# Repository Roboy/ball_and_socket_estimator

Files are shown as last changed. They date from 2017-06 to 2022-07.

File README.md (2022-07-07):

# Neural network ball socket estimator

## Install

* Pytorch `conda install pytorch torchvision torchaudio cudatoolkit=10.2 -c pytorch`

* `pip install -r requirements.txt`

## Data collection

Switch to `python` folder as your working directory `cd python`

* Generate data using `python particle_swarm.py --body_part BODY_PART`
  
 with `BODY_PART = {head, shoulder_left, shoulder_right, hand_left, hand_right}`

* Topics to record:

    - `/roboy/pinky/sensing/external_joint_states`
    - `/roboy/pinky/middleware/MagneticSensor`
    - `/tracking_loss`
    - `/roboy/pinky/control/cardsflow_joint_states`
    - `/roboy/pinky/simulation/joint_targets`

## Training

* Convert `bags` to `csv` using `write_dataset_from_bag.ipynb`

* Run `data_analysis.ipynb` to make sure all the inputs and outputs are correct

* Train an LSTM network using `training.ipynb`

## Prediction
`cd python`
* Run the trained network `python predict_lstm.py`

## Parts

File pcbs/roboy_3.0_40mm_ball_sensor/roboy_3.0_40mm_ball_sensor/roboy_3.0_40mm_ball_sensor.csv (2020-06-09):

Id | Designator | Package | Quantity | Designation | Supplier and ref
1 | U1,U2,U3,U4 | TLE493d | 4 | TLE493d | https://www.mouser.de/ProductDetail/Infineon-Technologies/TLE493DW2B6A0HTSA1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
2 | C1,C2,C3,C4 | C_0402_1005Metric | 4 | C | Any – 5V compliant
3 | J1 | TE-Connectivity_Micro-Match_connector_02x05_Pitch_1.27mm | 1 | Conn_01x10_Female | https://www.mouser.de/ProductDetail/TE-Connectivity/1-2178710-0
8 | FID1 | Fiducial_0.5mm_Mask1mm | 1 | FID1
9 | FID2 | Fiducial_0.5mm_Mask1mm | 1 | FID2
10 | FID3 | Fiducial_0.5mm_Mask1mm | 1 | FID3

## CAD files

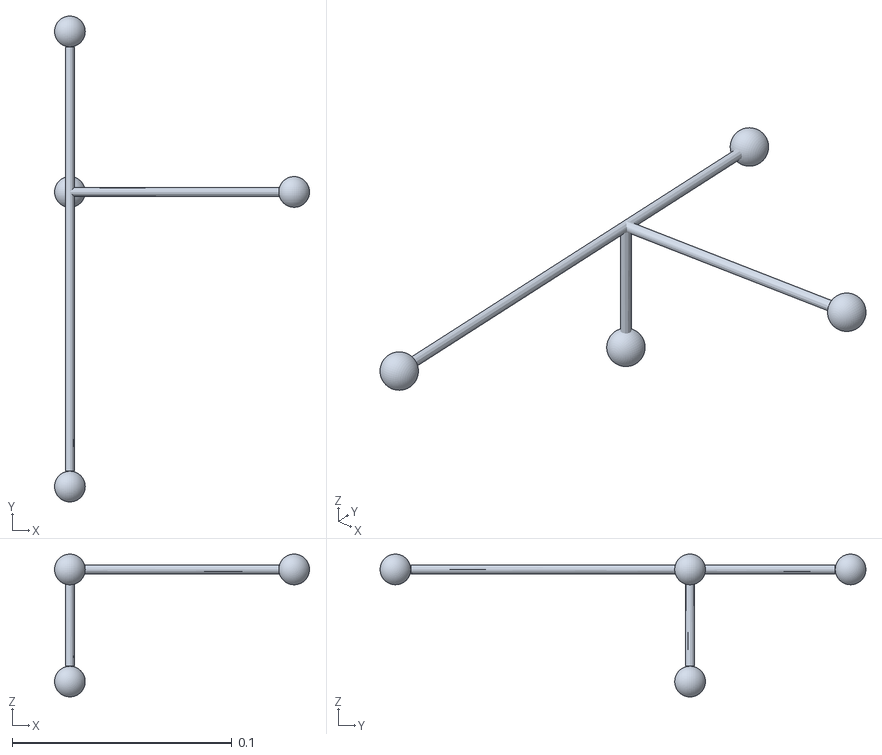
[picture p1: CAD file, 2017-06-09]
models/markermodel.STL
0.116 x 0.221 x 0.065

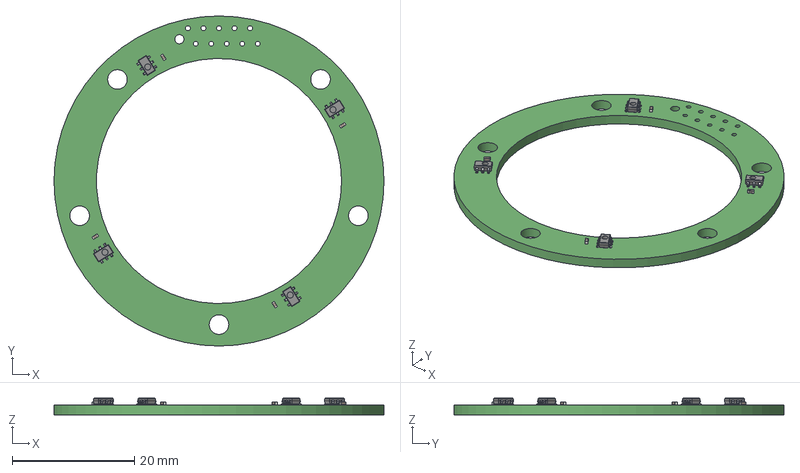
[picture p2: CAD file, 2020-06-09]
pcbs/roboy_3.0_40mm_ball_sensor/roboy_3.0_40mm_ball_sensor.step
54.0 x 54.0 x 2.75 mm

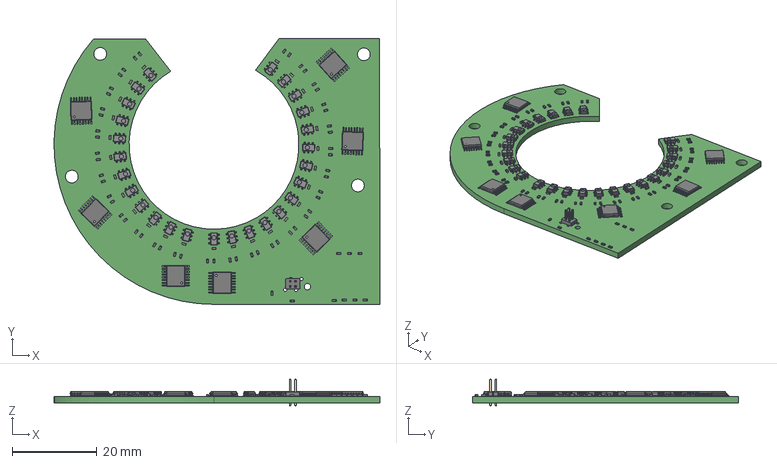
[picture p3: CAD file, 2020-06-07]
pcbs/roboy_3.0_40mm_magnetic_field_calibration/roboy_3.0_40mm_magnetic_field_calibration.step
76.8 x 62.6 x 6.30 mm

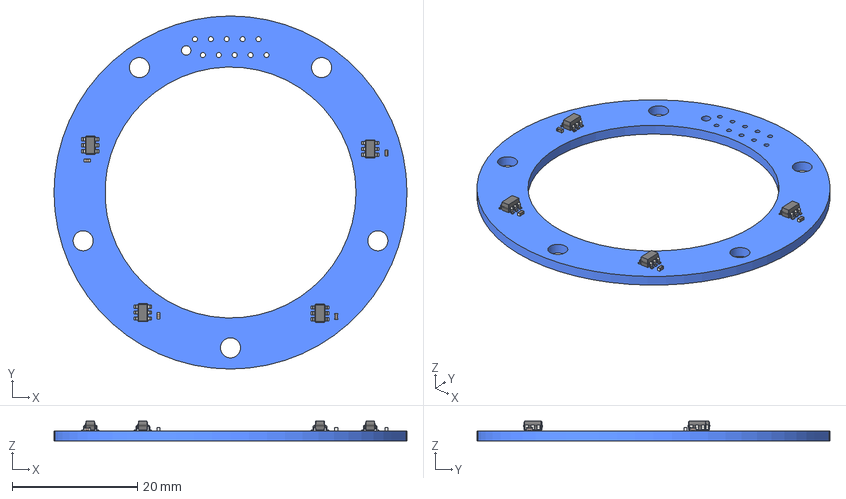
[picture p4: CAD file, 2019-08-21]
pcbs/roboy_3.0_40mm_ball_sensor/roboy_3.0_40mm_ball_sensor1.step
56.4 x 56.4 x 3.15 mm
Pcb
SOT_23_6_
SOT_23_6_001
SOT_23_6_002
C_0402_1005Metric_
C_0402_1005Metric_001
C_0402_1005Metric_002
C_0402_1005Metric_003
SOT_23_6_003

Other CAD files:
models/markermodel.obj

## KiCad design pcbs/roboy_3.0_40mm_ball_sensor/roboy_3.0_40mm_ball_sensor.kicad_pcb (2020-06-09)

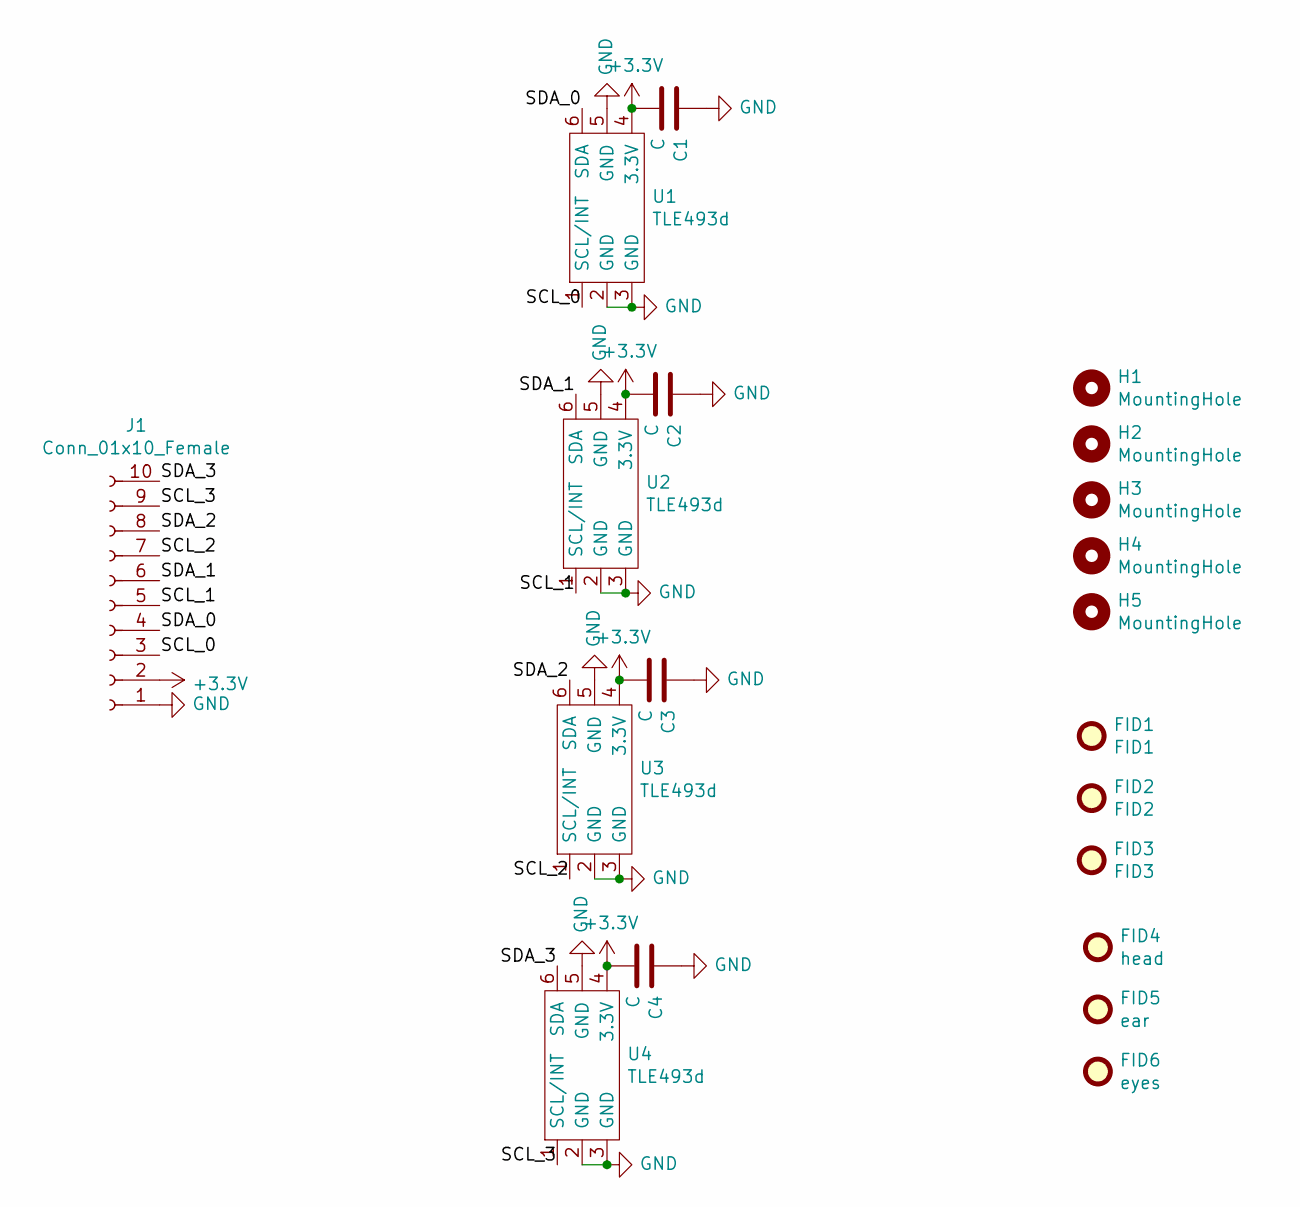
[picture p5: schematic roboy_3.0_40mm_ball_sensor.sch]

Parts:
C1, C2, C3, C4: C; C_0402_1005Metric
FID1: FID1; Fiducial_0.5mm_Mask1mm
FID2: FID2; Fiducial_0.5mm_Mask1mm
FID3: FID3; Fiducial_0.5mm_Mask1mm
FID4: head; R1_face_mask_5.5mm
FID5: ear; R1_ear_silk_5.5mm
FID6: eyes; R1_eyes_mask_5.5mm
H1, H2, H3, H4, H5: MountingHole; MountingHole_3.2mm_M3
J1: Conn_01x10_Female; TE-Connectivity_Micro-Match_connector_02x05_Pitch_1.27mm
U1, U2, U3, U4: TLE493d

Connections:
+3V3: C1.2, C2.2, C3.2, C4.2, J1.2, U1.4 (3.3V), U2.4 (3.3V), U3.4 (3.3V), U4.4 (3.3V)
/SCL_0: J1.3, U1.1 (SCL/INT)
/SCL_1: J1.5, U2.1 (SCL/INT)
/SCL_2: J1.7, U3.1 (SCL/INT)
/SCL_3: J1.9, U4.1 (SCL/INT)
/SDA_0: J1.4, U1.6 (SDA)
/SDA_1: J1.6, U2.6 (SDA)
/SDA_2: J1.8, U3.6 (SDA)
/SDA_3: J1.10, U4.6 (SDA)
GND: C1.1, C2.1, C3.1, C4.1, J1.1, U1.2 (GND), U1.3 (GND), U1.5 (GND), U2.2 (GND), U2.3 (GND), U2.5 (GND), U3.2 (GND), U3.3 (GND), U3.5 (GND), U4.2 (GND), U4.3 (GND), U4.5 (GND)

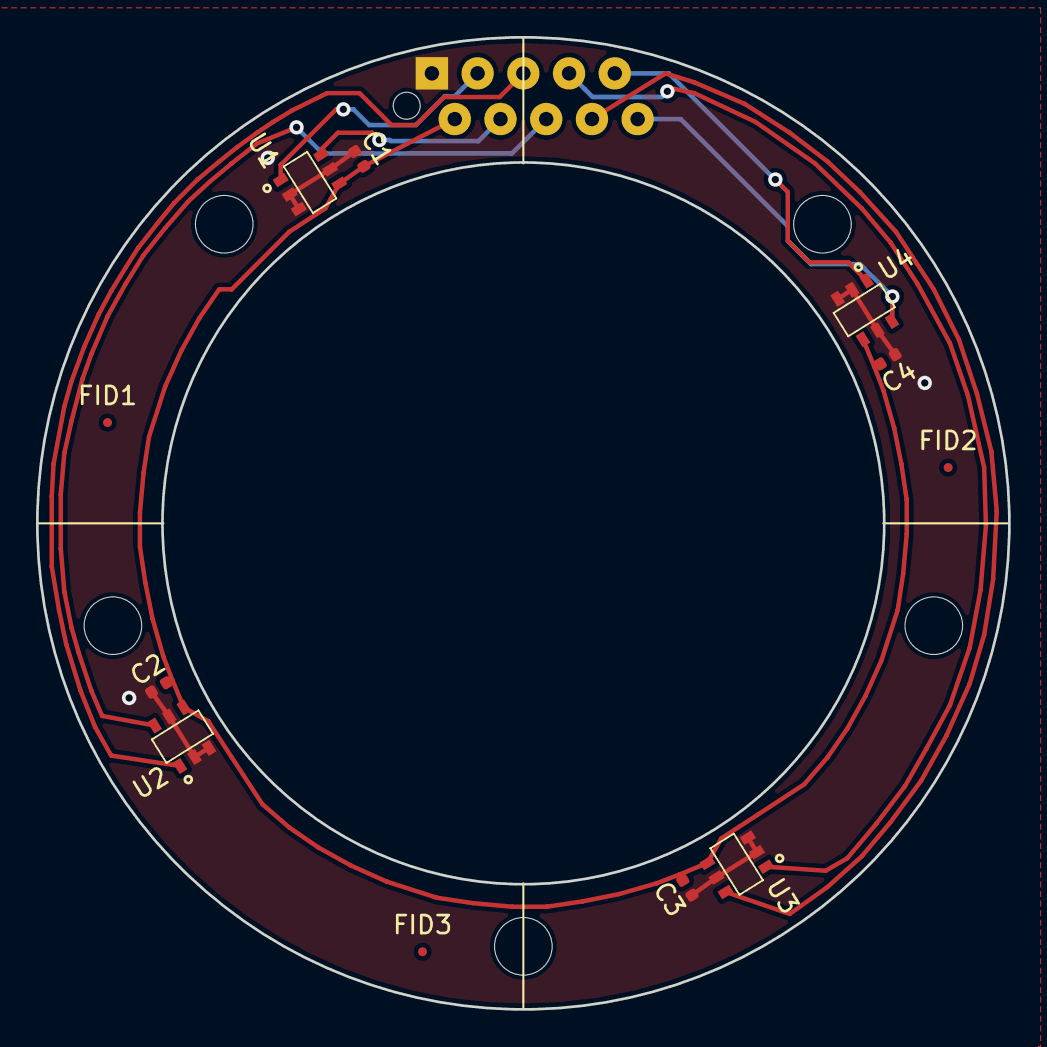
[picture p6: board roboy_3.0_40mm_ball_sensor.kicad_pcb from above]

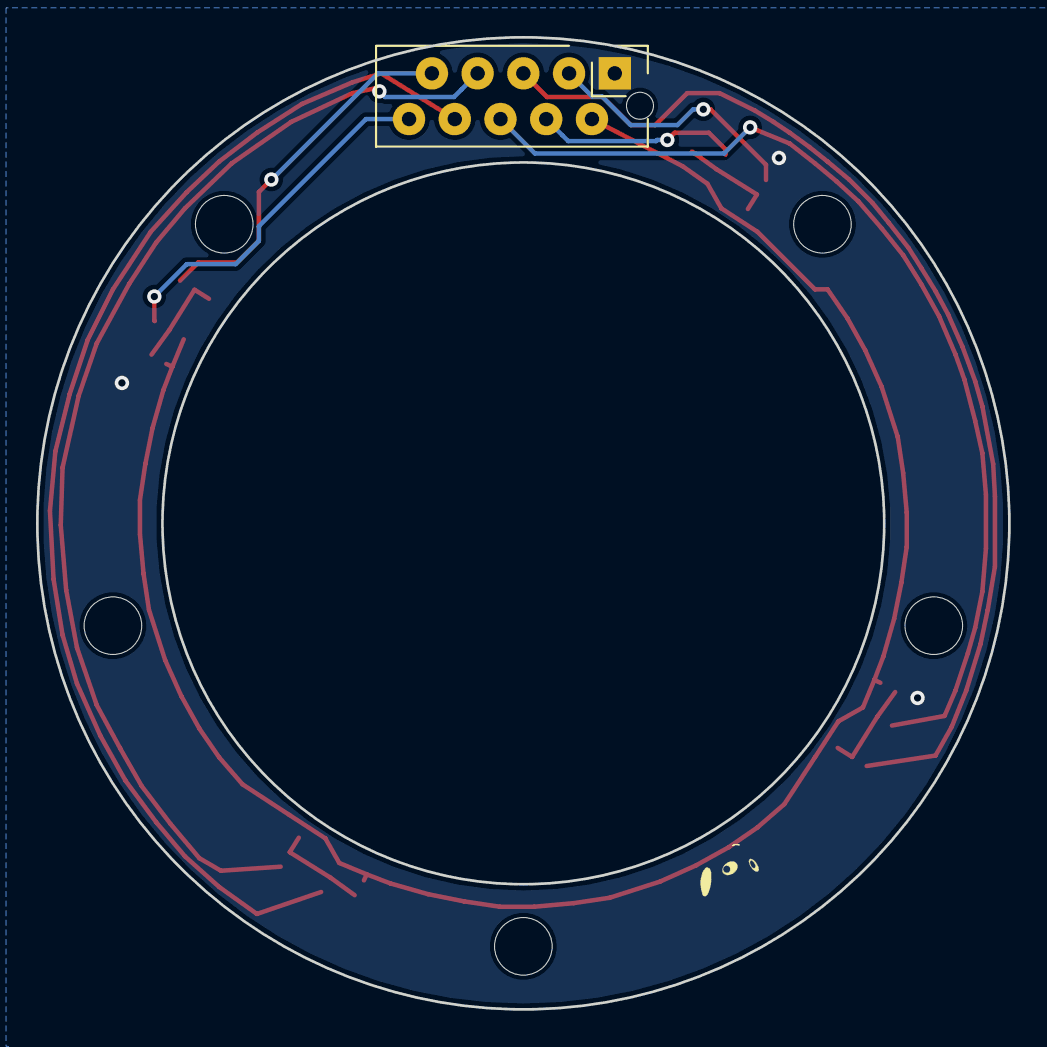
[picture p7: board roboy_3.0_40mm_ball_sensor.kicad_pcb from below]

Board: 2 copper layers, 54.0 x 54.0 mm, 20 parts (4 on the bottom side), 10 nets.

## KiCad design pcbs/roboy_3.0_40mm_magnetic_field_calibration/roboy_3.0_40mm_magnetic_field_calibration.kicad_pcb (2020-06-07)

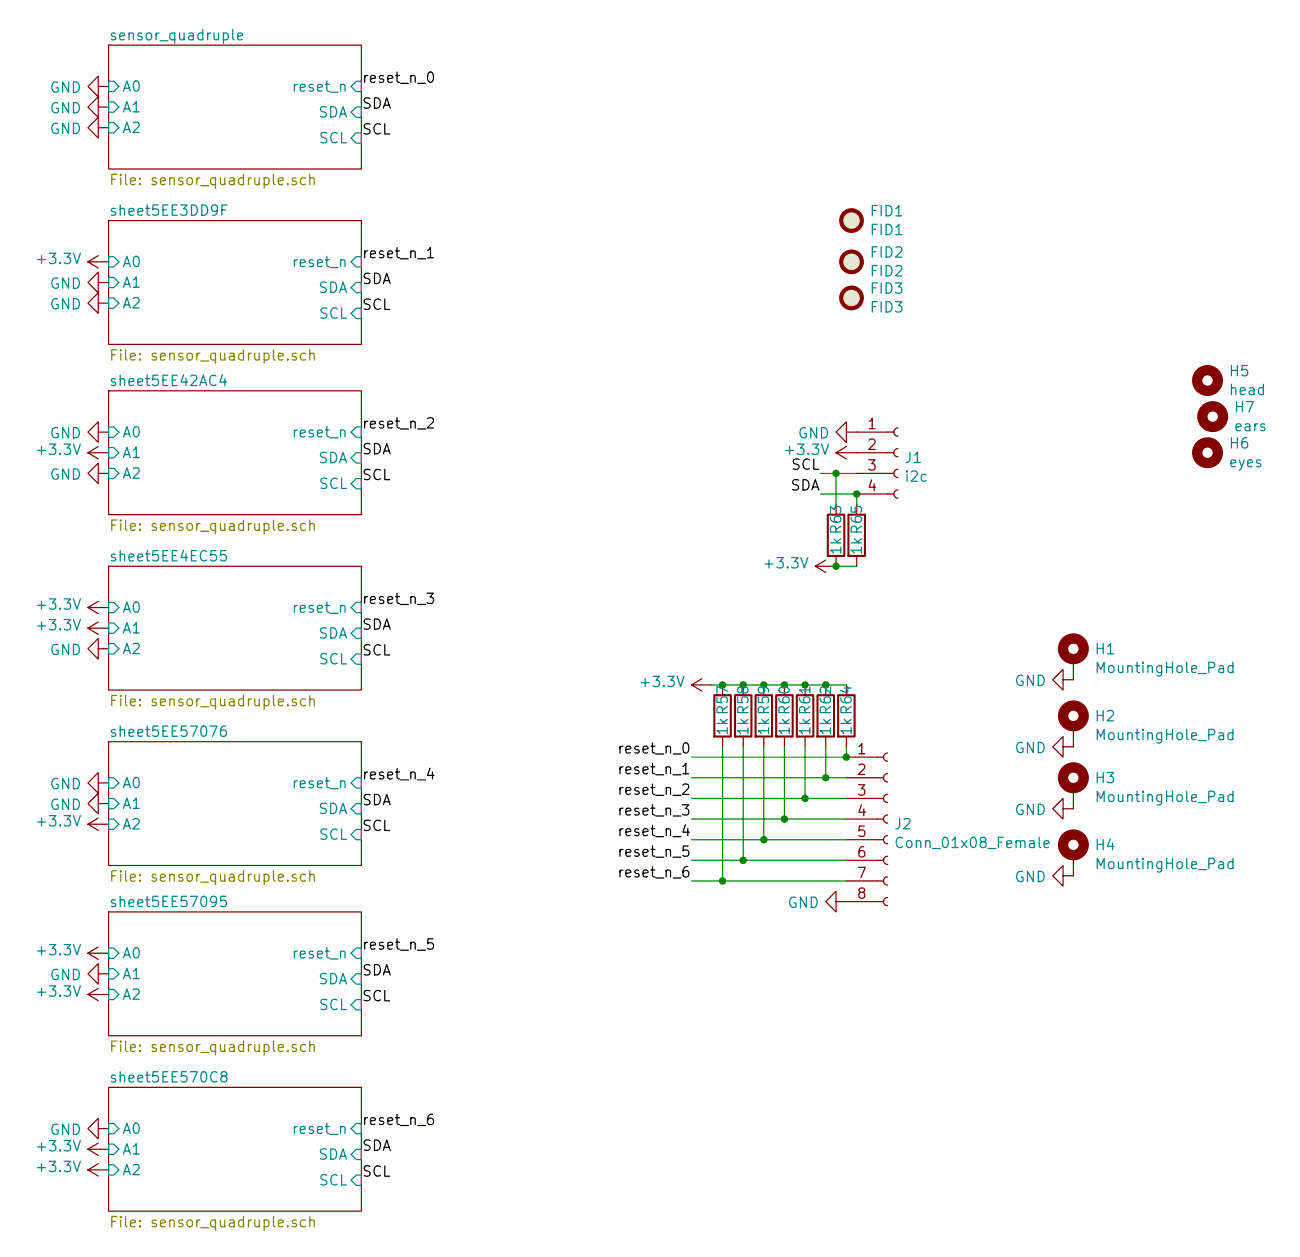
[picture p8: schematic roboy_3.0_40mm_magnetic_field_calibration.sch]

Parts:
FID1: FID1; Fiducial_0.75mm_Mask1.5mm
FID2: FID2; Fiducial_0.75mm_Mask1.5mm
FID3: FID3; Fiducial_0.75mm_Mask1.5mm
H1, H2, H3, H4: MountingHole_Pad; MountingHole_3mm_Pad
H5: head; R1_face_mask_5.5mm
H6: eyes; R1_eyes_mask_5.5mm
H7: ears; R1_ear_silk_5.5mm
J1: i2c; TE-Connectivity_Micro-Match_connector_02x02_Pitch_1.27mm
J2: Conn_01x08_Female; micro_match_female_8pos_SMT
R57, R58, R59, R60, R61, R62, R63, R64, R65: 1k; R_0402_1005Metric

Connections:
+3V3: J1.2, R57.1, R58.1, R59.1, R60.1, R61.1, R62.1, R63.2, R64.1, R65.2; also elsewhere on the board
/SCL: J1.3, R63.1; also elsewhere on the board
/SDA: J1.4, R65.1; also elsewhere on the board
/reset_n_0: J2.1, R64.2; also elsewhere on the board
/reset_n_1: J2.2, R62.2; also elsewhere on the board
/reset_n_2: J2.3, R61.2; also elsewhere on the board
/reset_n_3: J2.4, R60.2; also elsewhere on the board
/reset_n_4: J2.5, R59.2; also elsewhere on the board
/reset_n_5: J2.6, R58.2; also elsewhere on the board
/reset_n_6: J2.7, R57.2; also elsewhere on the board
GND: H1.1, H2.1, H3.1, H4.1, J1.1, J2.8; also elsewhere on the board

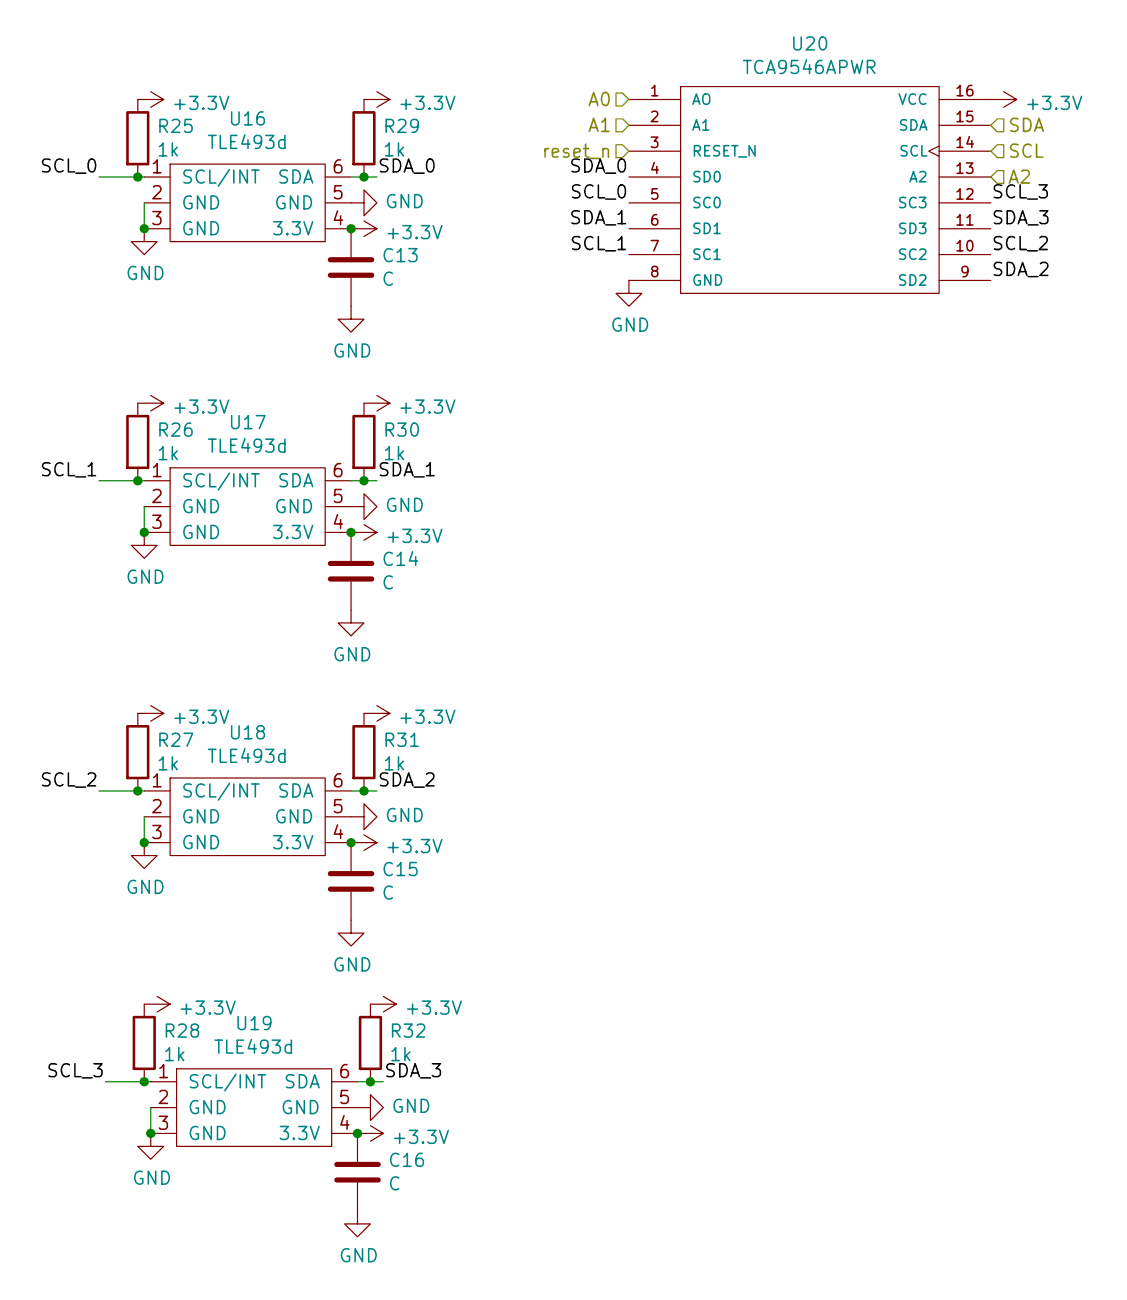
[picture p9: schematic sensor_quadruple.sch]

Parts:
C1, C2, C3, C4: C; C_0402_1005Metric
R1, R2, R3, R4, R5, R6, R7, R8: 1k; R_0402_1005Metric
U1, U2, U3, U4: TLE493d
U5: TCA9546APWR; SOP65P640X120-16N

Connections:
+3V3: C1.1, C2.1, C3.1, C4.1, R1.1, R2.1, R3.1, R4.1, R5.1, R6.1, R7.1, R8.1, U1.4 (3.3V), U2.4 (3.3V), U3.4 (3.3V), U4.4 (3.3V), U5.16 (VCC); also elsewhere on the board
/SCL: U5.14 (SCL); also elsewhere on the board
/SDA: U5.15 (SDA); also elsewhere on the board
/reset_n_0: U5.3 (RESET_N); also elsewhere on the board
/sensor_quadruple/SCL_0: R1.2, U1.1 (SCL/INT), U5.5 (SC0)
/sensor_quadruple/SCL_1: R2.2, U2.1 (SCL/INT), U5.7 (SC1)
/sensor_quadruple/SCL_2: R3.2, U3.1 (SCL/INT), U5.10 (SC2)
/sensor_quadruple/SCL_3: R4.2, U4.1 (SCL/INT), U5.12 (SC3)
/sensor_quadruple/SDA_0: R5.2, U1.6 (SDA), U5.4 (SD0)
/sensor_quadruple/SDA_1: R6.2, U2.6 (SDA), U5.6 (SD1)
/sensor_quadruple/SDA_2: R7.2, U3.6 (SDA), U5.9 (SD2)
/sensor_quadruple/SDA_3: R8.2, U4.6 (SDA), U5.11 (SD3)
GND: C1.2, C2.2, C3.2, C4.2, U1.2 (GND), U1.3 (GND), U1.5 (GND), U2.2 (GND), U2.3 (GND), U2.5 (GND), U3.2 (GND), U3.3 (GND), U3.5 (GND), U4.2 (GND), U4.3 (GND), U4.5 (GND), U5.1 (AO), U5.2 (A1), U5.8 (GND), U5.13 (A2); also elsewhere on the board

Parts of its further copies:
C5, C6, C7, C8, C9, C10, C11, C12, C13, C14, C15, C16, C17, C18, C19, C20, C21, C22, C23, C24, C25, C26, C27, C28: C; C_0402_1005Metric
R9, R10, R11, R12, R13, R14, R15, R16, R17, R18, R19, R20, R21, R22, R23, R24, R25, R26, R27, R28, R29, R30, R31, R32, R33, R34, R35, R36, R37, R38, R39, R40, R41, R42, R43, R44, R45, R46, R47, R48, R49, R50, R51, R52, R53, R54, R55, R56: 1k; R_0402_1005Metric
U6, U7, U8, U9, U11, U12, U13, U14, U16, U17, U18, U19, U21, U22, U23, U24, U26, U27, U28, U29, U31, U32, U33, U34: TLE493d
U10, U15, U20, U25, U30, U35: TCA9546APWR; SOP65P640X120-16N

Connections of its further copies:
+3V3: C5.1, C6.1, C7.1, C8.1, C9.1, C10.1, C11.1, C12.1, C13.1, C14.1, C17.1, C18.1, C19.1, C20.1, C21.1, C22.1, C23.1, C24.1, C25.1, C26.1, C27.1, C28.1, R9.1, R10.1, R11.1, R12.1, R13.1, R14.1, R15.1, R16.1, R17.1, R18.1, R19.1, R20.1, R21.1, R22.1, R23.1, R24.1, R25.1, R26.1, R29.1, R30.1, R33.1, R34.1, R35.1, R36.1, R37.1, R38.1, R39.1, R40.1, R41.1, R42.1, R43.1, R44.1, R45.1, R46.1, R47.1, R48.1, R49.1, R50.1, R51.1, R52.1, R53.1, R54.1, R55.1, R56.1, U6.4 (3.3V), U7.4 (3.3V), U8.4 (3.3V), U9.4 (3.3V), U10.1 (AO), U10.16 (VCC), U11.4 (3.3V), U12.4 (3.3V), U13.4 (3.3V), U14.4 (3.3V), U15.2 (A1), U15.16 (VCC), U16.4 (3.3V), U17.4 (3.3V), U20.1 (AO), U20.2 (A1), U20.16 (VCC), U21.4 (3.3V), U22.4 (3.3V), U23.4 (3.3V), U24.4 (3.3V), U25.13 (A2), U25.16 (VCC), U26.4 (3.3V), U27.4 (3.3V), U28.4 (3.3V), U29.4 (3.3V), U30.1 (AO), U30.13 (A2), U30.16 (VCC), U31.4 (3.3V), U32.4 (3.3V), U33.4 (3.3V), U34.4 (3.3V), U35.2 (A1), U35.13 (A2), U35.16 (VCC); also elsewhere on the board
/SCL: U10.14 (SCL), U15.14 (SCL), U20.14 (SCL), U25.14 (SCL), U30.14 (SCL), U35.14 (SCL); also elsewhere on the board
/SDA: U10.15 (SDA), U15.15 (SDA), U20.15 (SDA), U25.15 (SDA), U30.15 (SDA), U35.15 (SDA); also elsewhere on the board
/reset_n_1: U10.3 (RESET_N); also elsewhere on the board
/reset_n_2: U15.3 (RESET_N); also elsewhere on the board
/reset_n_3: U20.3 (RESET_N); also elsewhere on the board
/reset_n_4: U25.3 (RESET_N); also elsewhere on the board
/reset_n_5: U30.3 (RESET_N); also elsewhere on the board
/reset_n_6: U35.3 (RESET_N); also elsewhere on the board
/sheet5EE3DD9F/SCL_0: R9.2, U6.1 (SCL/INT), U10.5 (SC0)
/sheet5EE3DD9F/SCL_1: R10.2, U7.1 (SCL/INT), U10.7 (SC1)
/sheet5EE3DD9F/SCL_2: R11.2, U8.1 (SCL/INT), U10.10 (SC2)
/sheet5EE3DD9F/SCL_3: R12.2, U9.1 (SCL/INT), U10.12 (SC3)
/sheet5EE3DD9F/SDA_0: R13.2, U6.6 (SDA), U10.4 (SD0)
/sheet5EE3DD9F/SDA_1: R14.2, U7.6 (SDA), U10.6 (SD1)
/sheet5EE3DD9F/SDA_2: R15.2, U8.6 (SDA), U10.9 (SD2)
/sheet5EE3DD9F/SDA_3: R16.2, U9.6 (SDA), U10.11 (SD3)
/sheet5EE4EC55/SCL_0: R25.2, U16.1 (SCL/INT), U20.5 (SC0)
/sheet5EE4EC55/SCL_1: R26.2, U17.1 (SCL/INT), U20.7 (SC1)
/sheet5EE4EC55/SCL_2: U20.10 (SC2)
/sheet5EE4EC55/SCL_3: U20.12 (SC3)
/sheet5EE4EC55/SDA_0: R29.2, U16.6 (SDA), U20.4 (SD0)
/sheet5EE4EC55/SDA_1: R30.2, U17.6 (SDA), U20.6 (SD1)
/sheet5EE4EC55/SDA_2: U20.9 (SD2)
/sheet5EE4EC55/SDA_3: U20.11 (SD3)
/sheet5EE42AC4/SCL_0: R17.2, U11.1 (SCL/INT), U15.5 (SC0)
/sheet5EE42AC4/SCL_1: R18.2, U12.1 (SCL/INT), U15.7 (SC1)
/sheet5EE42AC4/SCL_2: R19.2, U13.1 (SCL/INT), U15.10 (SC2)
/sheet5EE42AC4/SCL_3: R20.2, U14.1 (SCL/INT), U15.12 (SC3)
/sheet5EE42AC4/SDA_0: R21.2, U11.6 (SDA), U15.4 (SD0)
/sheet5EE42AC4/SDA_1: R22.2, U12.6 (SDA), U15.6 (SD1)
/sheet5EE42AC4/SDA_2: R23.2, U13.6 (SDA), U15.9 (SD2)
/sheet5EE42AC4/SDA_3: R24.2, U14.6 (SDA), U15.11 (SD3)
/sheet5EE570C8/SCL_0: R49.2, U31.1 (SCL/INT), U35.5 (SC0)
/sheet5EE570C8/SCL_1: R50.2, U32.1 (SCL/INT), U35.7 (SC1)
/sheet5EE570C8/SCL_2: R51.2, U33.1 (SCL/INT), U35.10 (SC2)
/sheet5EE570C8/SCL_3: R52.2, U34.1 (SCL/INT), U35.12 (SC3)
/sheet5EE570C8/SDA_0: R53.2, U31.6 (SDA), U35.4 (SD0)
/sheet5EE570C8/SDA_1: R54.2, U32.6 (SDA), U35.6 (SD1)
/sheet5EE570C8/SDA_2: R55.2, U33.6 (SDA), U35.9 (SD2)
/sheet5EE570C8/SDA_3: R56.2, U34.6 (SDA), U35.11 (SD3)
/sheet5EE57076/SCL_0: R33.2, U21.1 (SCL/INT), U25.5 (SC0)
/sheet5EE57076/SCL_1: R34.2, U22.1 (SCL/INT), U25.7 (SC1)
/sheet5EE57076/SCL_2: R35.2, U23.1 (SCL/INT), U25.10 (SC2)
/sheet5EE57076/SCL_3: R36.2, U24.1 (SCL/INT), U25.12 (SC3)
/sheet5EE57076/SDA_0: R37.2, U21.6 (SDA), U25.4 (SD0)
/sheet5EE57076/SDA_1: R38.2, U22.6 (SDA), U25.6 (SD1)
/sheet5EE57076/SDA_2: R39.2, U23.6 (SDA), U25.9 (SD2)
/sheet5EE57076/SDA_3: R40.2, U24.6 (SDA), U25.11 (SD3)
/sheet5EE57095/SCL_0: R41.2, U26.1 (SCL/INT), U30.5 (SC0)
/sheet5EE57095/SCL_1: R42.2, U27.1 (SCL/INT), U30.7 (SC1)
/sheet5EE57095/SCL_2: R43.2, U28.1 (SCL/INT), U30.10 (SC2)
/sheet5EE57095/SCL_3: R44.2, U29.1 (SCL/INT), U30.12 (SC3)
/sheet5EE57095/SDA_0: R45.2, U26.6 (SDA), U30.4 (SD0)
/sheet5EE57095/SDA_1: R46.2, U27.6 (SDA), U30.6 (SD1)
/sheet5EE57095/SDA_2: R47.2, U28.6 (SDA), U30.9 (SD2)
/sheet5EE57095/SDA_3: R48.2, U29.6 (SDA), U30.11 (SD3)
GND: C5.2, C6.2, C7.2, C8.2, C9.2, C10.2, C11.2, C12.2, C13.2, C14.2, C17.2, C18.2, C19.2, C20.2, C21.2, C22.2, C23.2, C24.2, C25.2, C26.2, C27.2, C28.2, U6.2 (GND), U6.3 (GND), U6.5 (GND), U7.2 (GND), U7.3 (GND), U7.5 (GND), U8.2 (GND), U8.3 (GND), U8.5 (GND), U9.2 (GND), U9.3 (GND), U9.5 (GND), U10.2 (A1), U10.8 (GND), U10.13 (A2), U11.2 (GND), U11.3 (GND), U11.5 (GND), U12.2 (GND), U12.3 (GND), U12.5 (GND), U13.2 (GND), U13.3 (GND), U13.5 (GND), U14.2 (GND), U14.3 (GND), U14.5 (GND), U15.1 (AO), U15.8 (GND), U15.13 (A2), U16.2 (GND), U16.3 (GND), U16.5 (GND), U17.2 (GND), U17.3 (GND), U17.5 (GND), U20.8 (GND), U20.13 (A2), U21.2 (GND), U21.3 (GND), U21.5 (GND), U22.2 (GND), U22.3 (GND), U22.5 (GND), U23.2 (GND), U23.3 (GND), U23.5 (GND), U24.2 (GND), U24.3 (GND), U24.5 (GND), U25.1 (AO), U25.2 (A1), U25.8 (GND), U26.2 (GND), U26.3 (GND), U26.5 (GND), U27.2 (GND), U27.3 (GND), U27.5 (GND), U28.2 (GND), U28.3 (GND), U28.5 (GND), U29.2 (GND), U29.3 (GND), U29.5 (GND), U30.2 (A1), U30.8 (GND), U31.2 (GND), U31.3 (GND), U31.5 (GND), U32.2 (GND), U32.3 (GND), U32.5 (GND), U33.2 (GND), U33.3 (GND), U33.5 (GND), U34.2 (GND), U34.3 (GND), U34.5 (GND), U35.1 (AO), U35.8 (GND); also elsewhere on the board

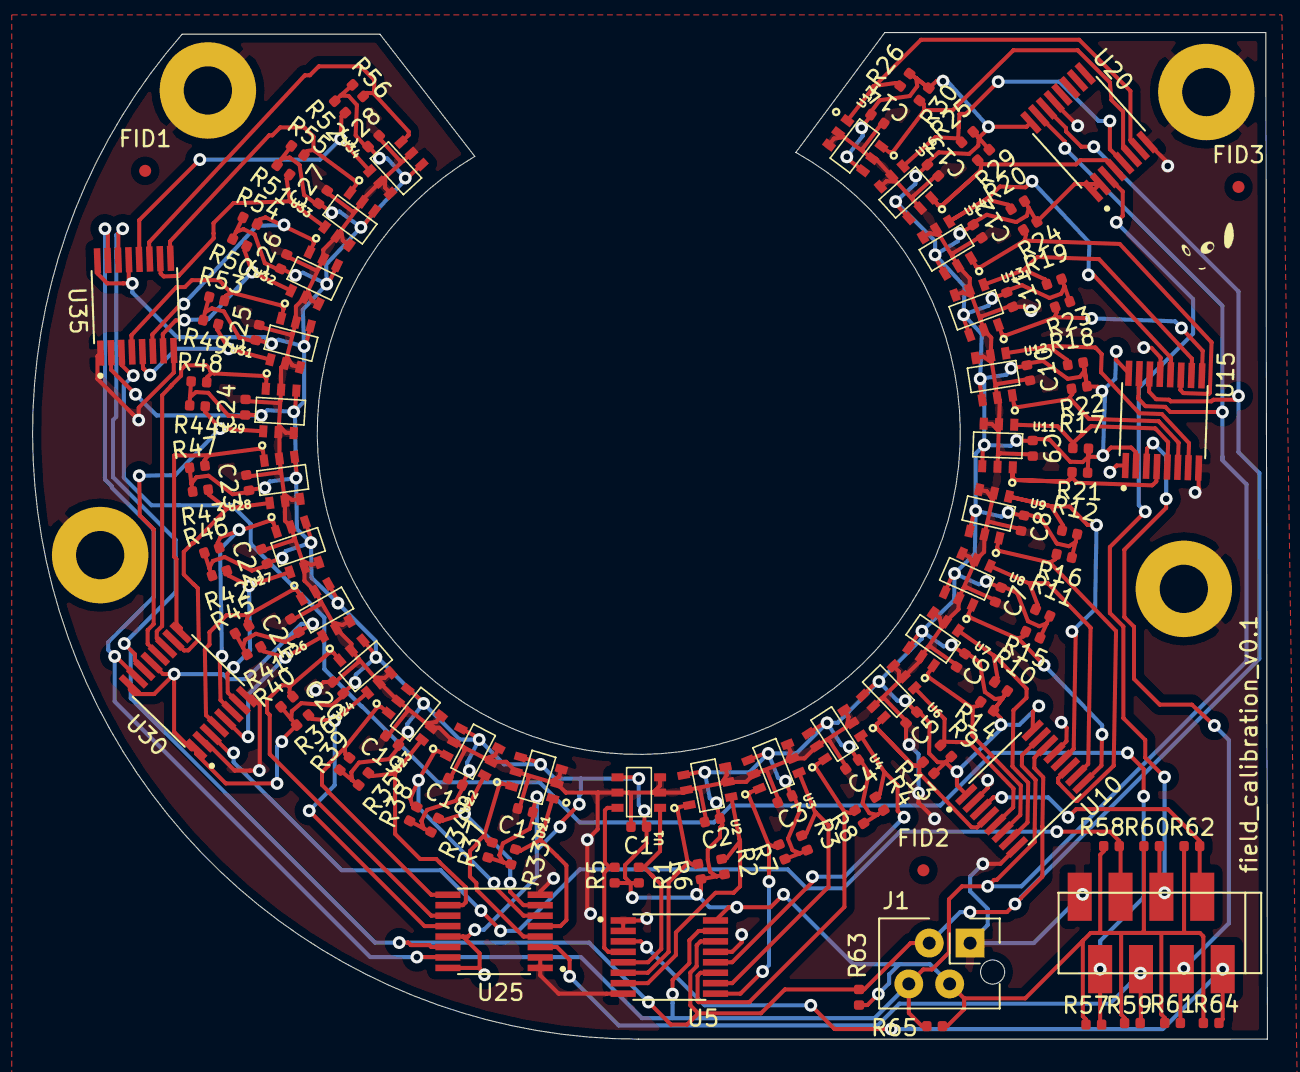
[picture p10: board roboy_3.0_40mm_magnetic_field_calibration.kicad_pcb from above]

Board: 2 copper layers, 76.8 x 62.6 mm, 132 parts (0 on the bottom side), 63 nets.

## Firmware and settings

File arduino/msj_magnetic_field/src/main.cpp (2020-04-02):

#include <ParallaxServo.hpp>
#define USE_USBCON
#include "ros.h"
#include "std_msgs/Int16.h"

ParallaxServo motor[] = {ParallaxServo(3,6),ParallaxServo(2,5)};
Servo servo;

ros::NodeHandle nh;

void motor0_CB( const std_msgs::Int16& msg){
  if(msg.data>=90 && msg.data<=270)
    motor[0].SetPoint(msg.data);
}

void motor1_CB( const std_msgs::Int16& msg){
  if(msg.data>=90 && msg.data<=270)
    motor[1].SetPoint(msg.data);
}

void motor2_CB( const std_msgs::Int16& msg){
  if(msg.data>=20 && msg.data<=160)
    servo.write(msg.data);
}

ros::Subscriber<std_msgs::Int16> sub[] = {ros::Subscriber<std_msgs::Int16>("motor_command/motor0", &motor0_CB ),
                                          ros::Subscriber<std_msgs::Int16>("motor_command/motor1", &motor1_CB ),
                                          ros::Subscriber<std_msgs::Int16>("motor_command/motor2", &motor2_CB )
                                        };

std_msgs::Int16 status_msg;
ros::Publisher p[] = {ros::Publisher("motor_status/motor0", &status_msg),ros::Publisher("motor_status/motor1", &status_msg),ros::Publisher("motor_status/motor2", &status_msg)};

void setup() {
  servo.attach(4);
  nh.initNode();
  for(int i=0;i<3;i++){
    nh.advertise(p[i]);
    nh.subscribe(sub[i]);
  }
  motor[0].SetPoint(180);
  motor[1].SetPoint(180);
  servo.write(90);
}

int counter;

void loop() {
  for(int i=0;i<2;i++){
    motor[i].update();
  }
  // delay(20);
  // delay(1000);
  if(counter++%10==0){
    for(int i=0;i<3;i++){
      if(i<2)
        status_msg.data = motor[i].GetAngle();
      else
        status_msg.data = servo.read();
      p[i].publish(&status_msg);
    }
  }
  nh.spinOnce();
}

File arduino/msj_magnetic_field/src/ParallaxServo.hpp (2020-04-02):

/* ParallaxServoControl
 * Controls the Parallax 360 Feedback Servo using a P-controller
 * by mriveralee - 7/2/2019
 * Based on datasheet for Parallax 360 Servo Motor
 * See here: https://www.parallax.com/sites/default/files/downloads/900-00360-Feedback-360-HS-Servo-v1.2.pdf
 *
 */
#include <Arduino.h>
#include <Servo.h>

class ParallaxServo{
public:
  ParallaxServo(int servo_pin, int feedback_pin):SERVO_PIN(servo_pin),SERVO_FEEDBACK_PIN(feedback_pin){
    SERVO.attach(SERVO_PIN);
    pinMode(SERVO_FEEDBACK_PIN, INPUT);
  }
  void update(){
    // Run pulseWidth measuring to figure out the current angle of the servo
    unsigned long tHigh = pulseIn(SERVO_FEEDBACK_PIN, HIGH);
    unsigned long tLow = pulseIn(SERVO_FEEDBACK_PIN, LOW);
    unsigned long  tCycle = tHigh + tLow;
    // Check if our cycle time was appropriate
    if (!(tCycle > 1000 && tCycle < 1200)) {
      // Invalid cycle time, so try pulse measuring again
      // Serial.println("Invalid cycle time");
      return;
    }
    // Calculate the duty cycle of the pulse
    float dutyCycle = (DUTY_SCALE) * ((float) tHigh / tCycle);
    float maxUnitsForCircle = UNITS_IN_FULL_CIRCLE - 1;

    // Calculate exact angle of servo
    currentAngle = maxUnitsForCircle - ((dutyCycle - DUTY_CYCLE_MIN) * UNITS_IN_FULL_CIRCLE) / ((DUTY_CYCLE_MAX - DUTY_CYCLE_MIN) + 1);

    // Clip current angle if we're somehow above or below range
    if (currentAngle < 0) {
      currentAngle = 0;
    } else if (currentAngle > maxUnitsForCircle) {
      currentAngle = maxUnitsForCircle;
    }

    // Handle quadrant wrap q1 -> q4 and q4 -> q1, to count turns
    if ((currentAngle < ANGLE_Q2_MIN) && (prevAngle > ANGLE_Q3_MAX)) {
      turns += 1;
    } else if ((prevAngle < ANGLE_Q2_MIN) && (currentAngle > ANGLE_Q3_MAX)) {
      turns -= 1;
    }

    // Save previous position
    prevAngle = currentAngle;
    errorAngle = targetAngle - currentAngle;
    integral += errorAngle*Ki;
    if(integral>integral_max)
      integral = integral_max;
    else if(integral<integral_min)
        integral = integral_min;
    // Simple P Controller
    float outputSpeed = errorAngle * Kp + (errorAngle-errorAngle_prev) * Kd + integral;
    errorAngle_prev = errorAngle;

    if (outputSpeed > output_max) {
      outputSpeed = output_max;
    } else if (outputSpeed < output_min) {
      outputSpeed = output_min;
    }
    // char str[200];
    // sprintf(str,"outputSpeed %f", outputSpeed);
    // Serial.println(str);

    outputSpeed = HOLD_STILL_PULSE_SPEED_US + outputSpeed;
    SERVO.writeMicroseconds(outputSpeed);
  }

  void SetPoint(int setpoint){
      targetAngle = setpoint;
  }
  int GetAngle(){
    return currentAngle;
  }
private:
  Servo SERVO;                        // The Parallax Servo
  byte SERVO_PIN = 2;                // The servo pin
  byte SERVO_FEEDBACK_PIN = 5;        // The feedback pin (from servo)

  float DUTY_SCALE = 1000;
  unsigned long DUTY_CYCLE_MIN = 29;  // 2.9% * DUTY_SCALE
  unsigned long DUTY_CYCLE_MAX = 971; // 9.71% * DUTY_SCALE
  float UNITS_IN_FULL_CIRCLE = 360;   // Because 360 degrees are in a circle

  // Tune the vars below for controlling how fast the servo gets to the right place and stays there
  int ERROR_ANGLE_OFFSET_US = 23;
  float integral = 0, integral_max = 10, integral_min = -10;
  float Kp = 1, Ki = 0.01, Kd = 0;

  int output_max = 200;    // Going Counter-clockwise a bit - can be smaller ( < -40)
  int output_min = -200;     // Going Clockwise  a bit - can be bigger (> 40)
  int HOLD_STILL_PULSE_SPEED_US = 1500;   // HOLD_STILL is for keeping the servo in place (no movement, don't change)

  // Angles for different quadrants around the unit circle (for counting number of turns)
  int ANGLE_Q2_MIN = 90;
  int ANGLE_Q3_MAX = 270;

  // Holds the current state
  int targetAngle = 0;                  // The angle we want the servo to go to
  int currentAngle = 0;                   // The angle the servo is at
  int prevAngle = 0;                      // The last angle the servo had
  int errorAngle = 0, errorAngle_prev = 0;                     // How off we are from the target angle
  int turns = 0;                          // How many times we've gone around the circle
};

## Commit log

2017-06-09 uh babay!
    [markermodel.STL, markermodel.obj]
2018-10-01 removed some trash
    [markermodel.STL, markermodel.obj]
2018-10-07 visualizing the magnetic field with point cloud library
2018-11-09 a bit jittery
2019-04-04 fix correct current euler angles
2019-08-18 ring sensor for neck
    [roboy_3.0_40mm_ball_sensor.cfg, roboy_3.0_40mm_ball_sensor.kicad_pcb, roboy_3.0_40mm_ball_sensor.sch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]
2019-08-19 layout finished
    [roboy_3.0_40mm_ball_sensor-B.Cu.gbr, roboy_3.0_40mm_ball_sensor-B.Mask.gbr, roboy_3.0_40mm_ball_sensor-B.Paste.gbr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]
2019-08-20 bigger ring
    [roboy_3.0_40mm_ball_sensor.kicad_pcb, roboy_3.0_40mm_ball_sensor.sch, roboy_3.0_40mm_ball_sensor1.step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]
2019-09-23 ordered on pcbway
    [roboy_3.0_40mm_ball_sensor-B_Cu.gbr, roboy_3.0_40mm_ball_sensor-B_Mask.gbr, roboy_3.0_40mm_ball_sensor-B_Paste.gbr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]
2020-04-02 actual pose estimation using real sensor data
2020-05-14 shoulder_left with locked joint
2020-05-19 inverted magnets
2020-05-22 6dof calibration
2020-05-24 with sim data generator and ball config in calibration
2020-05-24 finds simulated calibration values
2020-05-25 with real sensor value logger
2020-05-25 with cleaner magneticfieldcalibration class
2020-05-25 fixed sensor logger
2020-05-25 sensor selector
2020-05-26 with sensor merge and printout
    [balljoint_config_calibrated.yaml]
2020-05-26 with pose estimator uo to track
2020-05-27 two magnets arrangement giving decent results
    [magnet_A_45deg_calibrated.yaml]
2020-05-27 magnetic field collision
2020-05-27 magnetic collision multiprocessing
2020-05-28 three stages
2020-05-29 with magent arrangement optimizer draft
    [sensor_calibration.yaml]
2020-05-29 with calibration
    [sensor_calibration.yaml]
2020-05-29 using all data for training, d'oh
    [sensor_calibration.yaml]
2020-05-29 bigger joint space
2020-05-31 with getDP magnetic field simulation
2020-06-03 magnetic field visualization
    [sensor_calibration_7mm.yaml]
2020-06-05 with texture memory for magnetic field interpolation
2020-06-05 with actual magnetic field data interpolation
2020-06-06 with field calibration pcb
    [sensor_mux.sch, sensor_quadruple.sch]
2020-06-06 ordered on aisler
    [roboy_3.0_40mm_magnetic_field_calibration-B_Cu.gbr, roboy_3.0_40mm_magnetic_field_calibration-B_Mask.gbr, roboy_3.0_40mm_magnetic_field_calibration-B_Paste.gbr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]
2020-06-07 with 3d model
    [roboy_3.0_40mm_magnetic_field_calibration.kicad_pcb]
2020-06-09 sensors on circle
    [roboy_3.0_40mm_ball_sensor.kicad_pcb, roboy_3.0_40mm_ball_sensor.step]
2020-06-09 with sensors on circle
    [roboy_3.0_40mm_ball_sensor-B.Cu.gbr, roboy_3.0_40mm_ball_sensor-B.Mask.gbr, roboy_3.0_40mm_ball_sensor-B.Paste.gbr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]
2020-06-23 with magnetic field calibration draft
    [magnetic_field_calibration.yaml]
2020-06-24 with correct sensor alignment
2020-06-24 with sensor select
2020-06-24 invert sensor values on opposite pcb side
2020-07-01 with estimator on real sensor data
2020-07-01 the sensors are not aligned properly for some reason, but using one half of the pcb gives preliminary good position estimates
2020-07-06 with ball joint sensor config
2020-07-07 with clearer coordinate system
    [magnetic_field_calibration.yaml]
2020-07-08 trying to come up with a better interpolation function
    [magnetic_field_calibration.yaml]
2020-07-09 with almost correct interpolation using pycuda and real sensor data
2020-07-10 using sensor config
2021-05-26 Magnetic sensors to Euler Angles via Neural Network
    [balljoint_config_calibrated.yaml, magnet_A_45deg_calibrated.yaml]
2021-05-26 Updated network
    [balljoint_config_calibrated.yaml, magnet_A_45deg_calibrated.yaml]
2021-07-14 Adding moving average filter to remove outliers
2022-01-31 Add DVBF
    [metrics.csv]
2022-07-07 removed legacy python code, move readme to root
    [balljoint_config_calibrated.yaml, magnet_A_45deg_calibrated.yaml, metrics.csv]
